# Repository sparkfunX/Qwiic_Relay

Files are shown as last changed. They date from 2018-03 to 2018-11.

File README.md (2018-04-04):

SparkFun Qwiic Relay
========================================

SparkFun Qwiic Relay

[*SparkX Qwiic Relay (SPX-14668)*](https://www.sparkfun.com/products/14668)
Have you ever wanted to control something powerful? Have you ever needed to turn on/off a high voltage device from your Arduino? Now you can with the Qwiic Relay! This device allows you to control large power loads with simple I<sup>2</sup>C commands. The Qwiic Relay can handle 10 Amps at 120 Volts AC, perfect for large inductive loads like DC motors or blenders.

The Qwiic Relay comes with a default I<sup>2</sup>C address but can be changed with a simple command allowing you to control over 100 Qwiic Relays on a single bus!<sup>[1](#powerWarning)</sup>

The Qwiic Relay comes fully assembled and uses the simple [Qwiic](https://www.sparkfun.com/qwiic) interface. No soldering, no voltage translation, no figuring out which pin is SDA or SCL, just plug and go!

<div class="alert alert-warning"><b>Note:</b> Controlling high voltage (110/220VAC) requires certain precautions. A beginner can do it but if you're unsure then please consider the pre-made <a href="https://www.sparkfun.com/products/14236">IoT Power Relay</a>. It's not I<sup>2</sup>C but the IoT Power Relay contains shielding to prevent accidental shock.</div>

Footnote 1: Toggling lots of relays on a 3.3V bus can cause voltage spikes. An external power supply will be required.
Repository Contents
-------------------

* **/Documents** - Datasheets
* **/Firmware** - Latest firmware and examples. 
* **/Hardware** - Eagle design files (.brd, .sch)

License Information
-------------------

This product is _**open source**_! 

Please review the LICENSE.md file for license information. 

If you have any questions or concerns on licensing, please contact techsupport@sparkfun.com.

Please use, reuse, and modify these files as you see fit. Please maintain attribution to SparkFun Electronics and release under the same license.

Distributed as-is; no warranty is given.

- Your friends at SparkFun.

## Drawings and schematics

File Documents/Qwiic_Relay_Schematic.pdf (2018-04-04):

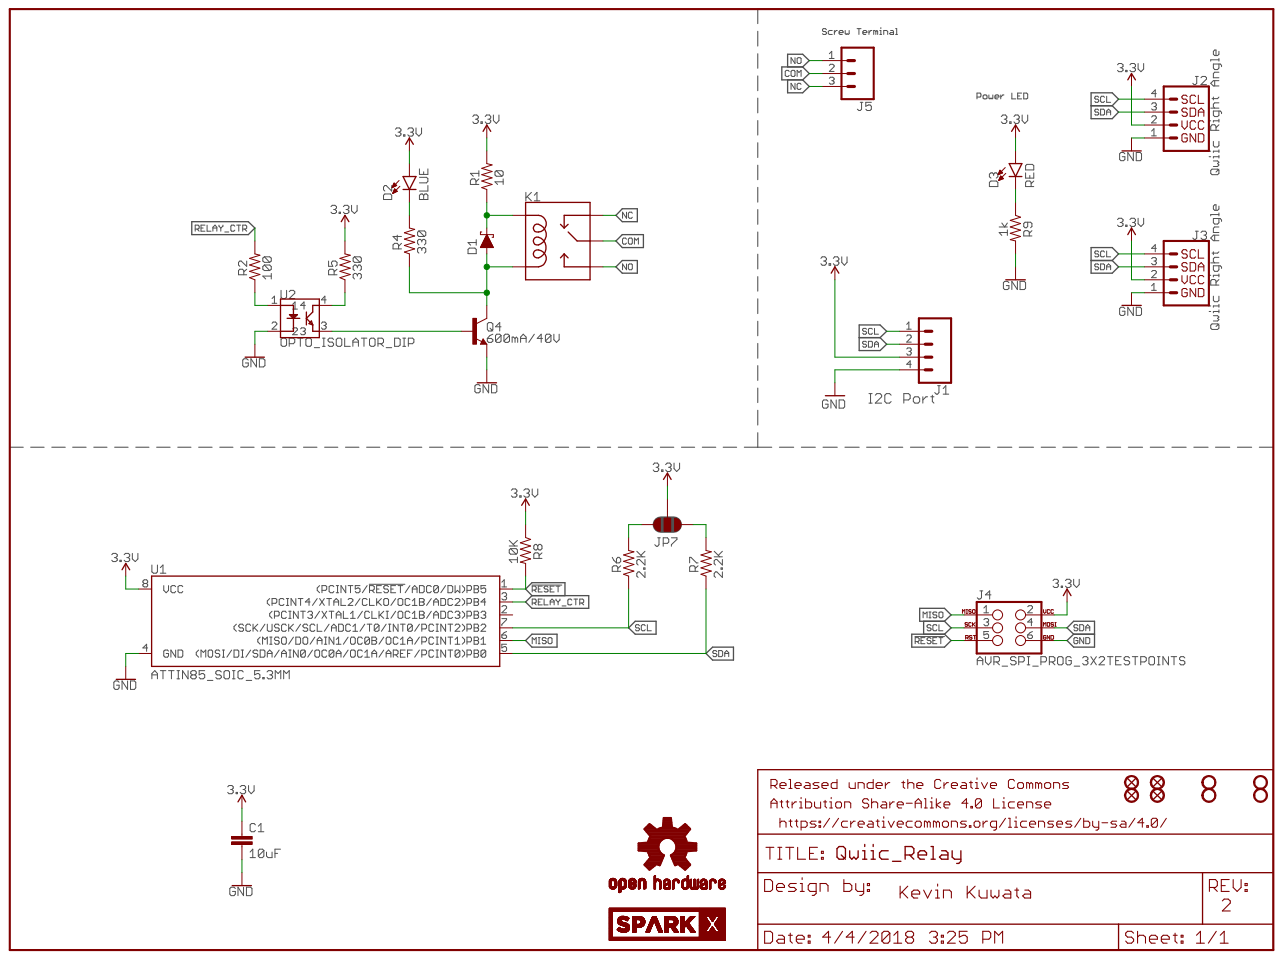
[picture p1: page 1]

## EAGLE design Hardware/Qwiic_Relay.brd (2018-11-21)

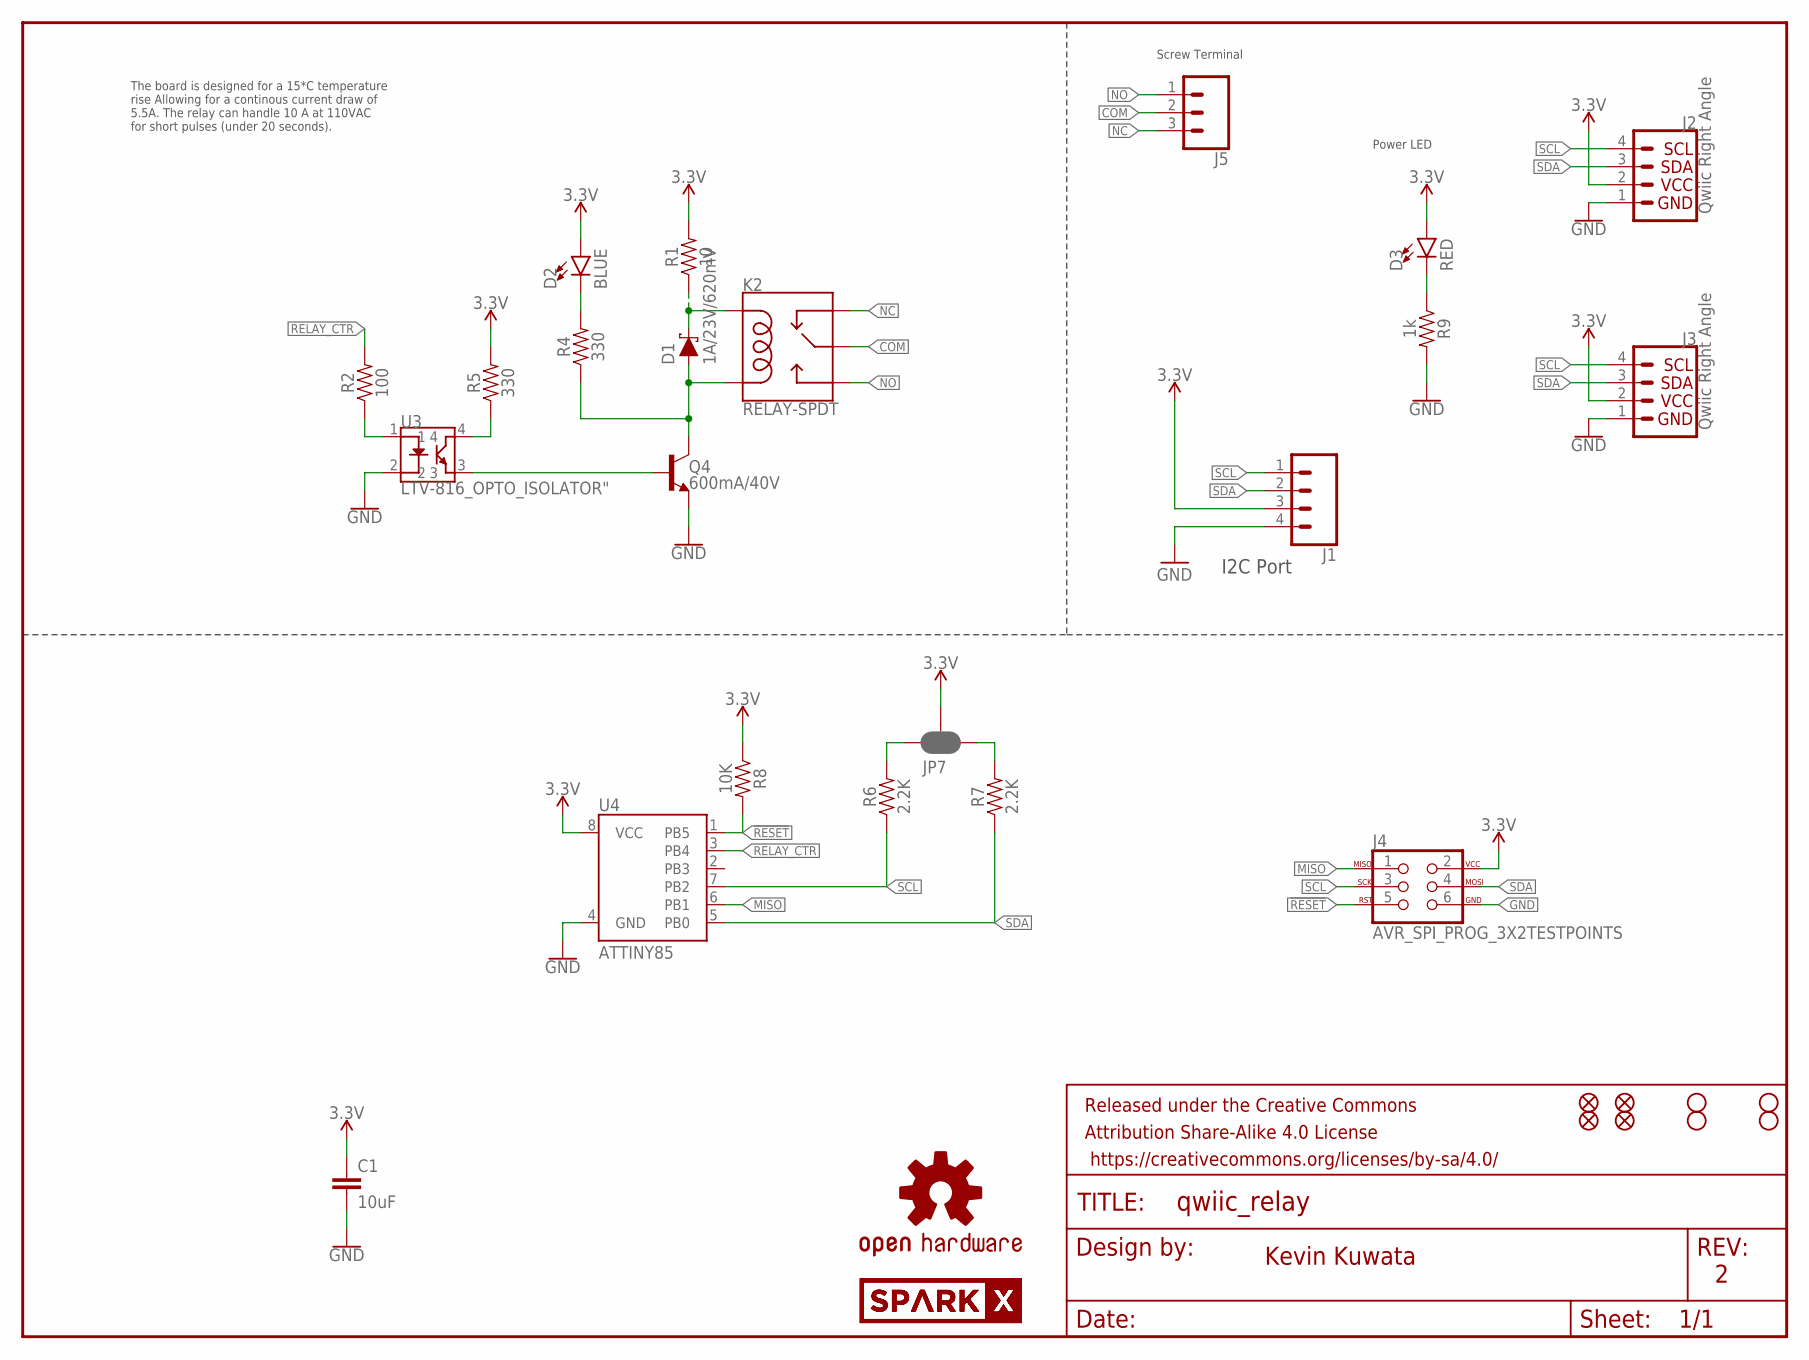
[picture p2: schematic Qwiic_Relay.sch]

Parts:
C1: 10uF; 0603
D1: 1A/23V/620mV; SOD-323
D2: BLUE; LED-0603
D3: RED; LED-0603
FRAME1: FRAME-LETTER; CREATIVE_COMMONS
J1: CONN_041X04_NO_SILK; 1X04_NO_SILK
J2, J3: Qwiic Right Angle; 1X04_1MM_RA
J4: AVR_SPI_PROG_3X2TESTPOINTS; 2X3_TEST_POINTS
J5: CONN_03-SCREW-5MM; SCREWTERMINAL-5MM-3
JP1, JP3, JP4, JP5: STAND-OFF
JP2, JP6, JP8, JP9: FIDUCIALUFIDUCIAL; MICRO-FIDUCIAL
JP7: JUMPER-SMT_3_2-NC_PASTE_SILK; SMT-JUMPER_3_2-NC_PASTE_SILK
K2: RELAY-SPDT; RELAY_G5LE
LOGO1: OSHW-LOGOMINI; OSHW-LOGO-MINI
Q4: 600mA/40V; SOT23-3
R1: 10; 0603
R2: 100; 0603
R4, R5: 330; 0603
R6, R7: 2.2K; 0603
R8: 10K; 0603
R9: 1k; 0603
U3: LTV-816_OPTO_ISOLATOR"; LTV-816_4PIN_DIP
U4: ATTINY85
U$3, U$4: SPARKX-LOGO4; SPARKX-MEDIUM

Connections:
3.3V: C1.1, D2.A, D3.A, J1.3, J2.2, J3.2, J4.2, JP7.2, R1.2, R5.2, R8.1, U4.8 (VCC)
!RESET: J4.5, R8.2, U4.1 (PB5)
COM: J5.2, K2.1 (MAIN)
GND: C1.2, J1.4, J2.1, J3.1, J4.6, Q4.2 (E), R9.2, U3.2, U4.4 (GND)
MISO: J4.1, U4.6 (PB1)
unnamed: Q4.1 (B), U3.3
unnamed: D1.A, K2.5 (COIL2), Q4.3 (C), R4.1
unnamed: R2.1, U3.1
unnamed: JP7.1, R7.2
unnamed: D1.C, K2.2 (COIL1), R1.1
unnamed: D2.C, R4.2
unnamed: R5.1, U3.4
unnamed: JP7.3, R6.2
unnamed: D3.C, R9.1
NC: J5.3, K2.4 (NC)
NO: J5.1, K2.3 (NO)
RELAY_CTR: R2.2, U4.3 (PB4)
SCL: J1.1, J2.4, J3.4, J4.3, R6.1, U4.7 (PB2)
SDA: J1.2, J2.3, J3.3, J4.4, R7.1, U4.5 (PB0)

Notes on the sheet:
Kevin Kuwata
Power LED
Screw Terminal
I2C Port
The board is designed for a 15*C temperature rise Allowing for a continous current draw of 5.5A. The relay can handle 10 A at 110VAC for short pulses (under 20 seconds).

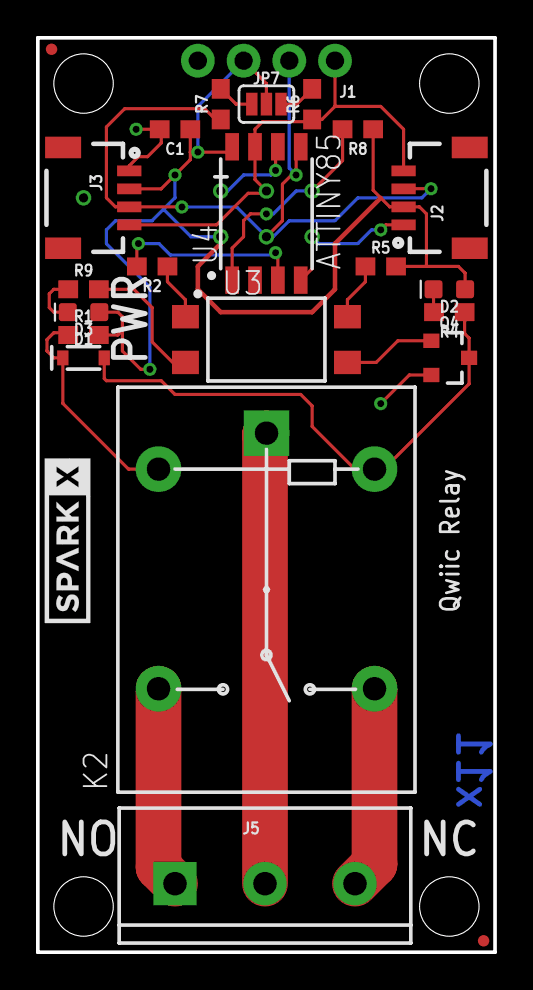
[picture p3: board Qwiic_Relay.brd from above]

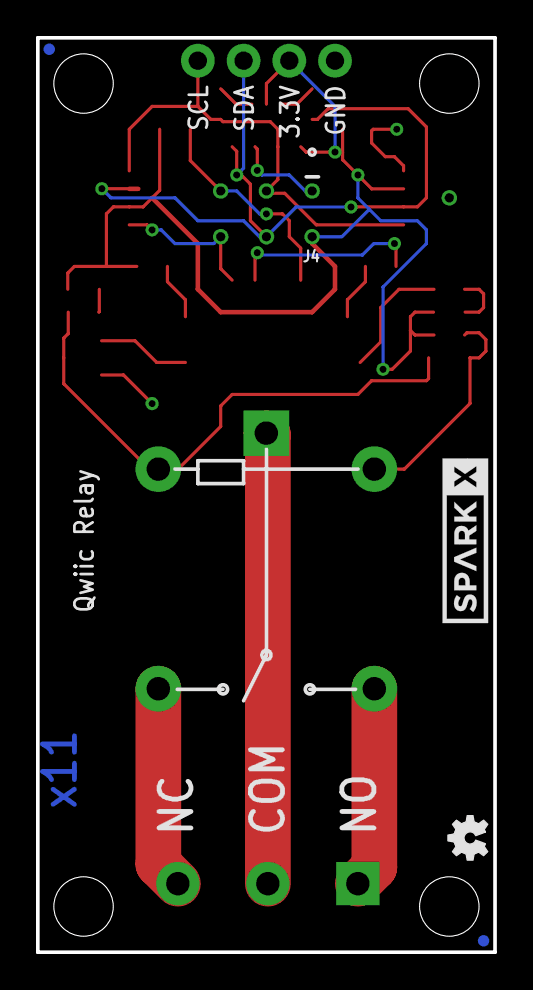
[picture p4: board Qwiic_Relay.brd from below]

Board: 2 copper layers, 25.4 x 50.8 mm, 34 parts (5 on the bottom side), 19 nets.

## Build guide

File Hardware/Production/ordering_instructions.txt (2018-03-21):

panel size, 78x103mm
PCB thickness, 1.6mm
number of layers, 2
soldermask color, Black
silkscreen color, White
oz copper, 1oz
finish, HASL lead free
stencils, top

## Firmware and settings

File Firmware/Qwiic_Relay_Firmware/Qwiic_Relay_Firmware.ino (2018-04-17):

/******************************************************************************
  Qwiic Relay Firmware
  Kevin Kuwata @ SparkX
  March 21, 2018
  https://github.com/sparkfunX/Qwiic_Relay
  Arduino 1.8.5

  This is the firmware on the Qwiic Relay. The default I2C Address is
  0x18;

******************************************************************************/
#include <TinyWire.h> //https://github.com/lucullusTheOnly/TinyWire
#include <EEPROM.h>


#define RELAY_PIN   4
 
#define SETTING_LOCATION_ADDRESS	1

volatile byte qwiicRelayAddress  =    0x18; //default

const byte relayAddressPin	=	3;



#define COMMAND_RELAY_OFF 			0x00
#define COMMAND_RELAY_ON 			0x01
#define COMMAND_CHANGE_ADDRESS 		0x03
#define COMMAND_FIRMWARE_VERSION 	0x04
#define COMMAND_STATUS 				0x05
#define COMMAND_HAS_BEEN_CHECKED 	0x99

const byte firmwareVersionMajor = 1;
const byte firmwareVersionMinor = 1;

volatile byte command = COMMAND_HAS_BEEN_CHECKED;
volatile byte address = COMMAND_HAS_BEEN_CHECKED;


void setup() {
	
  pinMode(relayAddressPin, INPUT);
  digitalWrite(relayAddressPin, HIGH); //internal pull up
  
  pinMode(RELAY_PIN, OUTPUT);
  digitalWrite(RELAY_PIN, LOW);
  
	
	if(digitalRead(relayAddressPin) == 0){
		qwiicRelayAddress = 0x19;
	}
	else{
  //Read EEPROM, is it empty (0xFF)? or does it have a value?
  qwiicRelayAddress =  EEPROM.read(SETTING_LOCATION_ADDRESS);
		if (qwiicRelayAddress == 0xFF) {
			//EEPROM has never been written before, use the default address 0x18.
		qwiicRelayAddress = 0x18; //default
		}
	}

  TinyWire.begin(qwiicRelayAddress);
  TinyWire.onReceive(receiveEvent); // register event
  TinyWire.onRequest(onI2CRequest);
}

void loop() {
}

/*========================================================*/
//        ISR
/*========================================================*/

// When the master initiates a command and data to slave
//		ie) the master says 0x01, then sends a 1, means command: 0x01 then the slave listens for the next thing, which is the relay state 1
void receiveEvent(int bytesReceived) {
  byte count = 0;
  while (TinyWire.available() > 0) {
    if (count == 0) {
      command = TinyWire.read();

      if (command == COMMAND_RELAY_ON) {
        digitalWrite(RELAY_PIN, HIGH);
        command = COMMAND_HAS_BEEN_CHECKED;
      }
      else if (command == COMMAND_RELAY_OFF) {
        digitalWrite(RELAY_PIN, LOW);
        command = COMMAND_HAS_BEEN_CHECKED;
      }
    }
    else if (count == 1) {
      if (command == COMMAND_CHANGE_ADDRESS) {
        byte address = TinyWire.read();

        if (address > 0x07 && address < 0x78) {
          //valid address, update and save to EEPROM
          qwiicRelayAddress = address;

          EEPROM.write(SETTING_LOCATION_ADDRESS, qwiicRelayAddress);
          TinyWire.begin(qwiicRelayAddress);
        }
      }
    }
    else {
      TinyWire.read(); //read the data coming in but ignore it.
    }
    count++;
  }
}// end of receive ISR



//When the master requests data from the slave, this
//    ISR is triggered.

void onI2CRequest() {
  //not sure if this will work because the master sends 0x04, then the salve enters the RX event isr
  // then goes to main, sets the flag. then if that happens slower than versionFlag we have a race condition.
  if (command == COMMAND_FIRMWARE_VERSION) {
    //TinyWire.send(firmwareVersion);// tiny wire can't send multiple bytes.
    TinyWire.send(firmwareVersionMajor);
    TinyWire.send(firmwareVersionMinor);

    command = COMMAND_HAS_BEEN_CHECKED;
  }
  else if (command == COMMAND_STATUS) {
    if (digitalRead(RELAY_PIN) == HIGH)
      TinyWire.send(COMMAND_RELAY_ON);
    else
      TinyWire.send(COMMAND_RELAY_OFF);

    command = COMMAND_HAS_BEEN_CHECKED;
  }
}

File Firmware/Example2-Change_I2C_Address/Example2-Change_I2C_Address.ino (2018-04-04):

/******************************************************************************
  Qwiic Relay Example 2 - Change I2C Address
  Kevin Kuwata @ SparkX
  March 21, 2018
  https://github.com/sparkfunX/Qwiic_Relay
  Arduino 1.8.5

  This sketch demonstrates how to change the I2C Address
  of the Qwiic Relay. The new address will be saved to the
  Relay's EEPROM.

  The factory default slave address is 0x18.

  Note: If the Qwiic Relay is connected but unresponsive, try Example 3 - I2C_Scanner
  to find the current address of the Relay.

  Only valid address can be saved to the Relay's EEPROM. If an invalid address is
  sent, the Relay will ignore the address change without notifying the user.

******************************************************************************/
#include <Wire.h>
#define COMMAND_RELAY_OFF 				  0x00
#define COMMAND_RELAY_ON 				    0x01
#define COMMAND_CHANGE_ADDRESS 			0x03



volatile byte qwiicRelayAddress = 0x19;     //Default Address


void setup() {
  Serial.begin(9600);
  Serial.println("Qwiic Relay Master Awake");
  Wire.begin(); // join the I2C Bus


  Wire.beginTransmission(qwiicRelayAddress); // transmit to device
  //check here for an ACK from the slave
  if (Wire.endTransmission() != 0 ) {
    Serial.println("Check Connections. Slave not found.");
  }

  Serial.println("Qwiic Relay found!");

  relayOn(); // Turn on the Relay (at address 0x18)
  delay(1000);
  byte error = changeAddress(0x18); // Change the Relay's address to 0x19
  relayOff(); // Turn off the Relay (at address 0x19)
  delay(1000);
  changeAddress(0x00); // Try to change address to Invalid Address.

  if (error != true) {
    Serial.println("!!!!! invalid address" );
  }
  Serial.println("success");
}

void loop() {
}


// changeAddress() takes a 7 bit I2C Address
// and writes it to the Relay. This function
// checks to see if the address is between
// 0x07 and 0x78. If valid, the new address is
// saved to the Relay's EEPROM. If not valid
// address is not changed and is ignored.
// This function returns true if successful and
// false if unsuccessful.
boolean changeAddress(byte address) {
  Wire.beginTransmission(qwiicRelayAddress);
  //check here for an ACK from the slave
  if (Wire.endTransmission()  != 0) {
    Serial.println("Check Connections. No slave found.");
    return (false);
  }

  //check if valid address.
  if (address < 0x07 || address > 0x78) {
    Serial.println("Invalid I2C address");
    return (false);
  }
  //valid address
  Wire.beginTransmission(qwiicRelayAddress);
  Wire.write(COMMAND_CHANGE_ADDRESS);
  qwiicRelayAddress = address;
  Wire.write(qwiicRelayAddress);
  Wire.endTransmission();
  return (true); //Success!
}




// RelayOn() turns on the relay at the SLAVE_ADDRESS
// Checks to see if a slave is connected and prints a
// message to the Serial Monitor if no slave found.
void relayOn() {
  Wire.beginTransmission(qwiicRelayAddress);
  Wire.write(COMMAND_RELAY_ON);
  Wire.endTransmission();
}


// RelayOff() turns off the relay at the SLAVE_ADDRESS
// Checks to see if a slave is connected and prints a
// message to the Serial Monitor if no slave found.
void relayOff() {
  Wire.beginTransmission(qwiicRelayAddress);
  Wire.write(COMMAND_RELAY_OFF);
  Wire.endTransmission();
}

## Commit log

2018-02-28 ordered board
    [Qwiic_Relay-Panel.GBL, Qwiic_Relay-Panel.GBO, Qwiic_Relay-Panel.GBP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]
2018-03-21 added Example 1- Basic Control and Example 2- Change Address
    [Qwiic_Relay-Panel.brd, Qwiic_Relay.brd, Qwiic_Relay.sch]
2018-03-21 added examples and firmware
    [Qwiic_Relay-Panel.brd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]
2018-03-28 adding changes to firmware, before a fetch
    [Qwiic_Relay-Panel.brd]
2018-03-28 minor changes to setup() making it clearer for user and forcing a known state of the relay
    [Qwiic_Relay-Panel.brd]
2018-03-29 making changes to the firmware from the review, but have proven to be broken going to revert back a commit
    [Example1-BasicControl.ino.ino, Qwiic_Relay_Firmware.ino]
2018-03-29 added a testForConnectivity() function which tests in the setup and then freezes if there is no relay attached. Cleaned unnecessary comments
2018-03-29 update example 2. removed comments, and moved test case into setup so that we are not writing to eeprom a billion times
2018-03-29 changed example 4: to be more concise, removed all extra comments in examples 1, 2, and 4, example 3 is a direct copy of the i2c scanner from arduino playground
2018-04-02 fixed the relay bug where the relay would fail to trigger, I had accidently set up the pinmode twice. I needed to set the relay low not the pinmode low.
    [Qwiic_Relay_Firmware.ino]
2018-04-02 fixed bug when transfering from array based ISR handlers to 2 bytes command / address. the problem was i was servicing the ISR, and checking 2 checks for 1 byte of data, when in reality I need to do 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
    [Qwiic_Relay_Firmware.ino]
2018-04-02 the ISR for Rx event is not making it into my case statement with flag: versionFlag == 1, maybe i need a delay between the write, and request. so the flag has time to change. it is volatile
2018-04-02 worked on adding getting version out of the firmware, changed the onI2C request handler so that i send over [hardcoded] version number. tinyWire doesn't work well with sending more than 1 byte. need 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
    [Qwiic_Relay_Firmware.ino]
2018-04-03 Nate helped cleaned this up quite a bit, removed all flags so code is deterministic, and fixed the firmware float version issue. I call it the Beau trick. Take your high and low bytes, cast one to a 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
    [Qwiic_Relay_Firmware.ino]
2018-04-04 Revert "Nate helped cleaned this up quite a bit, removed all flags so code is deterministic, and fixed the firmware float version issue. I call it the Beau trick. Take your high and low bytes, cast o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
    This reverts commit 34565a5c9fb479b53dd11eaa8e6bcc8cf3833fe0.
    [Qwiic_Relay_Firmware.ino]
2018-04-04 reverted back to an older version, then i went through the firmware and corrected the git conflicts, then i compiled. now i'm going to verify the other examples still work before flashing new firmwar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
    [Optoisolator-v12.sch, Qwiic_Relay.brd, Qwiic_Relay.sch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]
2018-04-04 Formatting with Arduino
    Formatted code in Arduino IDE. Ready to be merged with master.
2018-04-04 cleaned up repo
    cleaned up the folders, fixed file name for example 1.
    [Example1-Basic_Control.ino, Example2-Change_I2C_Address.ino, Example3-I2C_Scanner.ino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]
2018-04-04 updated repo
    - Removed unnecessary eagle documents
    - added IoT relay as related product
    - included a pdf of the schematic
    - added relay datasheet
    [Optoisolator-v12.brd, Optoisolator-v12.sch, Qwiic_Relay.sch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]
2018-04-04 deleted redundant panel filies
    [myPanel.GBL, myPanel.GBO, myPanel.GBS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]
2018-04-04 added pdf
    added pdf of schematic into the hardware folder,changed read me, and added more details to the schematic about max currents.
    [Qwiic_Relay.brd, Qwiic_Relay.sch]
2018-04-17 implemented external jumper for addressing
    If the external jumper is closed the address is forced to 0x19. If the jumper is open then the eeprom will be read and if blank, the default address 0x18 will be used.
    if the jumper is closed and the address is changed it will be stored in eeprom but the device will not use that address.
2018-11-20 updated relay to use the sealed version
    [Qwiic_Relay.brd, Qwiic_Relay.sch]
2018-11-21 updated parts for sparkle parts
    [Qwiic_Relay.brd, Qwiic_Relay.sch]

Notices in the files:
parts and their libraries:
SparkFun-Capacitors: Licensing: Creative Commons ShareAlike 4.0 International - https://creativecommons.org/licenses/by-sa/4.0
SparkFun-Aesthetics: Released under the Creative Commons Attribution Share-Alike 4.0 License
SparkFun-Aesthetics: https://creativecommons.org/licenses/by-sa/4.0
